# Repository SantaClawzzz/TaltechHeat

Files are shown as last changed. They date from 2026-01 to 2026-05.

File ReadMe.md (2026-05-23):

# Introduction

DIY reflow solder plate controller design, where the actual plate connects with XT30 connector.<br>
Based on this [`PROJECT`](https://github.com/DerSpatz/PCB-reflow-solder-heat-plate)

All PDFs, images, and exports are under the [OUTPUTS](https://github.com/SantaClawzzz/TaltechHeat/tree/master/Outputs) folder

The BOM file is also there and the basket for it is [HERE](https://www.mouser.ee/Tools/SavedCart/Share?AccessID=80928401d5)

## Hardware:<br> 
- **20V 5A max**
- USB-C PD **(Power Delivery)** - `[STUSB4500]`
- MCU programmed with SWD - `[STM32F103C6]`
- 5V switching regulator - `[AP64060ZQ]`

## Pinout

|  User | Pin  |
|---|---|
| BUT1 |  PC13  |
| BUT2 |  PC14  |
| PC15 |  PC15  |

| Signal | Pin  | Function |
|---|---|---|
| SCL | PB8  | I2C1_SCL |
| SDA | PB9  | I2C1_SDA |
| PD_ALERT | PB10 | |
| PD_RST | PB11 | |
| PWM | PB13 | TIM1_CH1N |
| PD_GPIO | PB14 | |
| PD_ATTACH  | PB15 | |
| VCC-DIV | PA3  | ADC1_IN3 |
| TEMP1 | PA4  | ADC1_IN4 | 
| TEMP2 | PA5  | ADC1_IN5 |
| POWER_OK_3 | PA8  | |
| UART1_RX | PA9  | USART1_TX |
| UART1_TX | PA10 | USART1_RX |
| SWDIO | PA13 | SYS_JTMS-SWDIO |
| SWCLK | PA14 | SYS_JTCK-SWCLK |

## Problems

- SWD pins not brought out to headers
- MOSFET too small, can't handle current (PD FET)
- PWM not on PWM capable pin
- Routing issues

- [More detail](https://docs.google.com/document/d/1i9aejrMOuASw6s5gDh6MXbNuGSY3eZ5T1xDJf5HSRbU/edit?tab=t.0)

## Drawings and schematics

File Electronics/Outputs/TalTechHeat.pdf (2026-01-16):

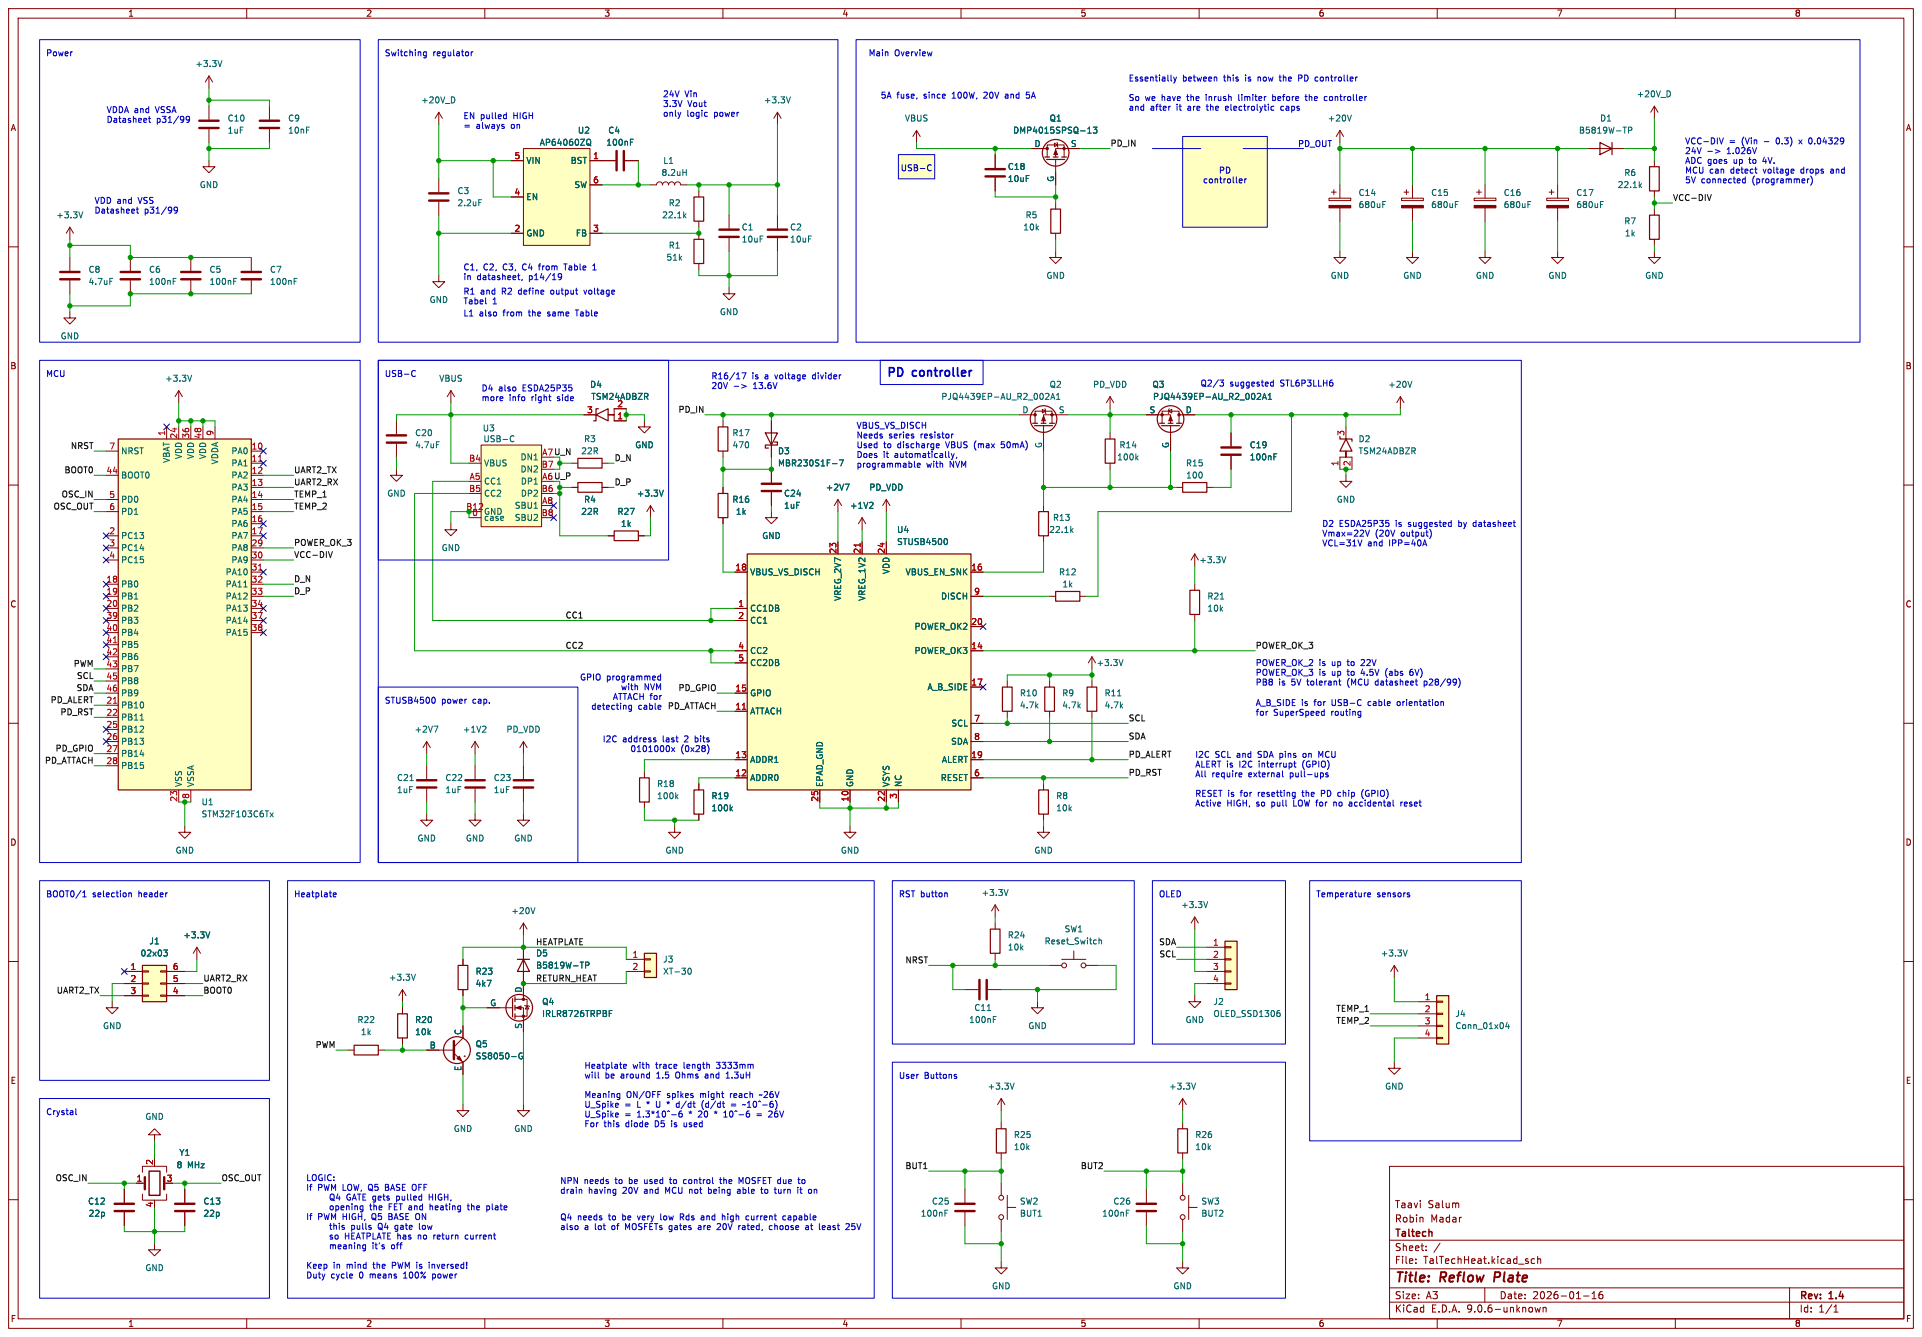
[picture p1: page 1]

24V Vin
3.3V Vout only logic power

controller 5A fuse, since 100W, 20V and 5A

ADC goes up to 4V. MCU can detect voltage drops and

USB-C GPIO programmed with NVM

R1 and R2 define output voltage Tabel 1 C1, C2, C3, C4 from Table 1
4.7uFGND

L1 also from the same Table

1 VDD 24 VSS 23 VDD 36 VSSA
PD_RST OSC_IN

3 VBUS_EN_SNK 16 DISCH 9 POWER_OK2 20 POWER_OK3 14 A_B_SIDE 17 SCL 7 SDA 8 ALERT 19 RESET 6 U4STUSB4500 R12

3 VBUS_EN_SNK 16 DISCH 9 POWER_OK2 20 POWER_OK3 14 A_B_SIDE 17 SCL 7 SDA 8 ALERT 19 RESET 6 R19

A_B_SIDE is for USB-C cable orientation
for SuperSpeed routing

I2C SCL and SDA pins on MCU

drain having 20V and MCU not being able to turn it on Q4 needs to be very low Rds and high current capable

File: TalTechHeat.kicad_sch Sheet: / Taltech Robin Madar Taavi Salum

If PWM HIGH, Q5 BASE ON

also a lot of MOSFETs gates are 20V rated, choose at least 25V

Id: 1/1 Title: Reflow Plate

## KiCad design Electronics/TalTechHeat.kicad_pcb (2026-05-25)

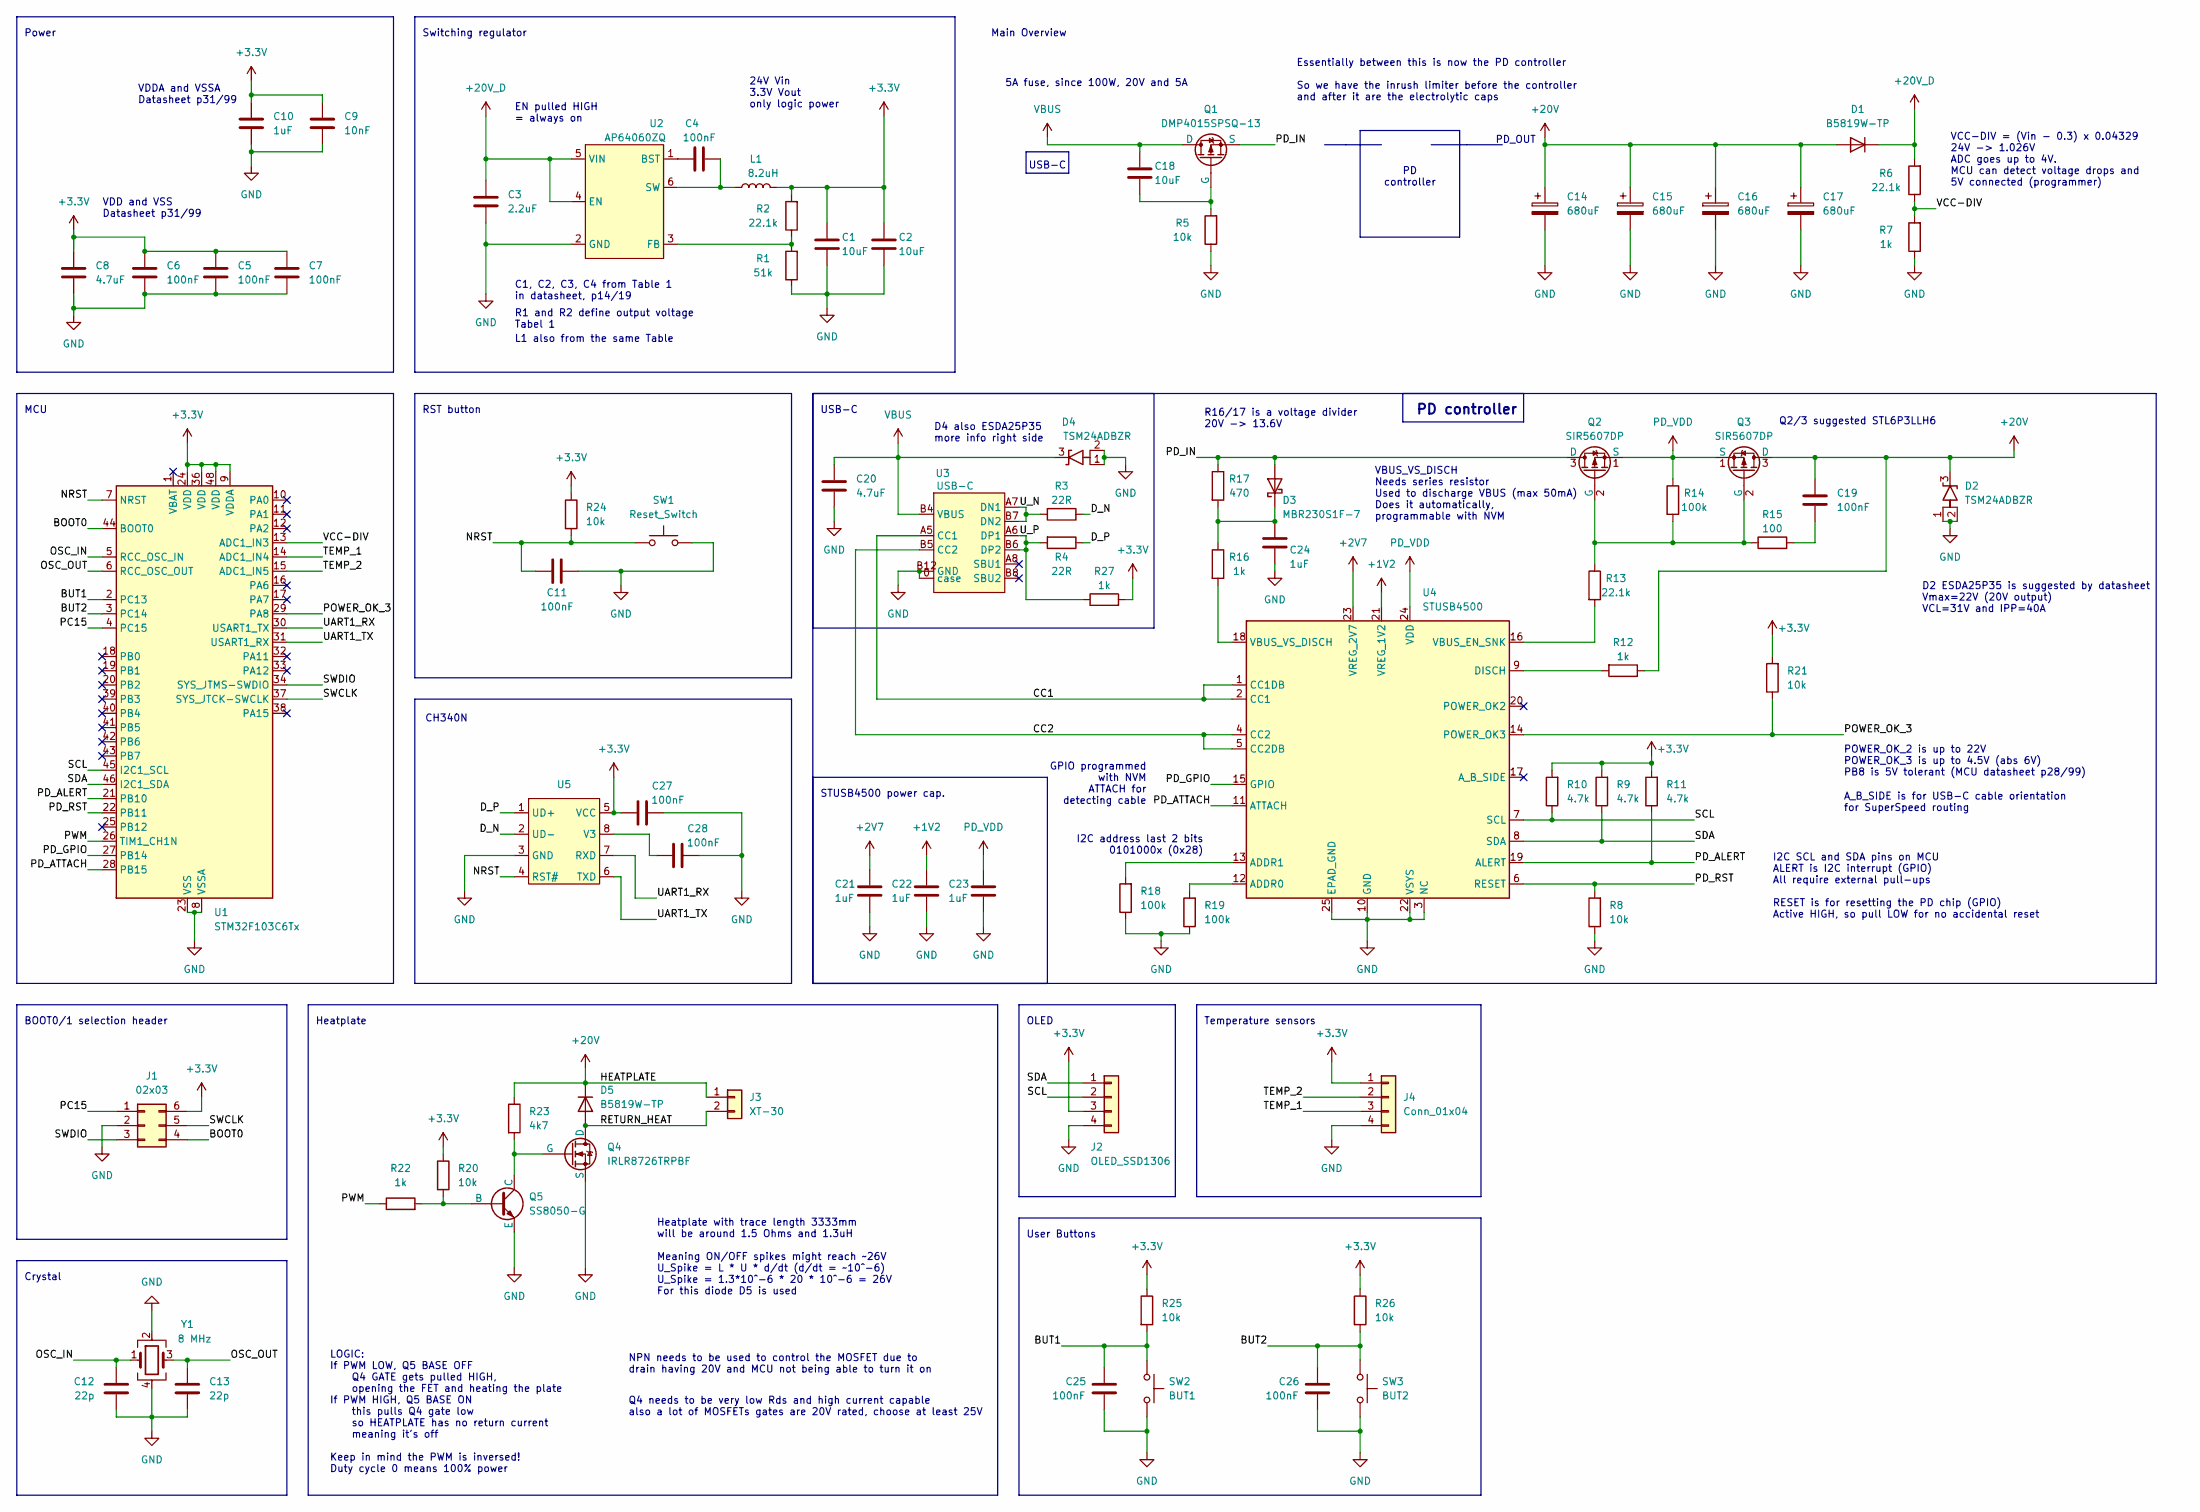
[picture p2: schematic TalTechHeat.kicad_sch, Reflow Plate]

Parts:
C1, C2, C18: 10uF; C_1206_3216Metric_Pad1.33x1.80mm_HandSolder; MPN CL31B106KBHNNNE; Mouser_PN 187-CL31B475KBHNFNE
C3: 2.2uF; C_0805_2012Metric_Pad1.18x1.45mm_HandSolder; MPN CL31B225KBHNNNE; Mouser_PN 187-CL31B225KBHNNNE
C4, C5, C6, C7, C11, C19, C25, C26, C27, C28: 100nF; C_0603_1608Metric_Pad1.08x0.95mm_HandSolder; MPN CL10B104KC8NNNC; Mouser_PN 187-CL10B104KC8NNNC
C8, C20: 4.7uF; C_1206_3216Metric_Pad1.33x1.80mm_HandSolder; MPN CL31B475KBHNFNE; Mouser_PN 187-CL31B475KBHNFNE
C9: 10nF; C_0603_1608Metric_Pad1.08x0.95mm_HandSolder; MPN CL10B103KB8NNNL; Mouser_PN 187-CL10B103KB8NNNL
C10, C21, C22, C23, C24: 1uF; C_0805_2012Metric_Pad1.18x1.45mm_HandSolder; MPN CL21B105KBFNNNE; Mouser_PN 187-CL21B105KBFNNNE
C12, C13: 22p; C_0603_1608Metric_Pad1.08x0.95mm_HandSolder; MPN CL10C220JB8NNNC; Mouser_PN 187-CL10C220JB8NNNC
C14, C15, C16, C17: 680uF; 10mm CAP; MPN UHW1V681MPD; Mouser_PN 647-UHW1V681MPD
D1, D5: B5819W-TP; D_SOD-123; MPN B5819W-TP; Mouser_PN 833-B5819W-TP
D2, D4: TSM24ADBZR; SOT-23-3; MPN TSM24ADBZR; Mouser_PN 595-TSM24ADBZR
D3: MBR230S1F-7; D_SOD-123F; MPN MBR230S1F-7; Mouser_PN 621-MBR230S1F-7
J1: 02x03; PinHeader_2x03_P2.54mm_Vertical; MPN 10129381-906004BLF; Mouser_PN 649-1012938190604BLF
J2: OLED_SSD1306; OLED_128x32; MPN SSD1306 128x32; Mouser_PN (Endal olemas)
J3: XT-30; AMASS_XT30PW-F_1x02_P2.50mm_Horizontal; MPN XT30PW-F; Mouser_PN (Endal olemas)
J4: Conn_01x04; JST_PH_B4B-PH-K_1x04_P2.00mm_Vertical; MPN B4B-PH-K-S(LF)(SN); Mouser_PN 306-B4BPHKSLFSNPP
L1: 8.2uH; L_Vishay_IHLP-2525; MPN IHLP2525BDER8R2M01; Mouser_PN 70-IHLP2525BDER8R2M1
Q1: DMP4015SPSQ-13; DMP4015; MPN DMP4015SPSQ-13; Mouser_PN 621-DMP4015SPSQ-13
Q2, Q3: SIR5607DP
Q4: IRLR8726TRPBF; TO-252.2; MPN IRLR8726TRPBF; Mouser_PN 942-IRLR8726TRPBF
Q5: SS8050-G; SOT-23-3; MPN SS8050-G; Mouser_PN 750-SS8050-G
R1: 51k; R_0603_1608Metric_Pad0.98x0.95mm_HandSolder; MPN RMC16K513FTP; Mouser_PN 791-RMC16K513FTP
R2, R6, R13: 22.1k; R_0603_1608Metric_Pad0.98x0.95mm_HandSolder; MPN RT0603FRE1322K1L; Mouser_PN 603-RT0603FRE1322K1L
R3, R4: 22R; R_0603_1608Metric_Pad0.98x0.95mm_HandSolder; MPN RMC1/16K22R0FTP; Mouser_PN 791-RMC1/16K22R0FTP
R5, R8: 10k; R_0603_1608Metric_Pad0.98x0.95mm_HandSolder; MPN AF0603FR-0710KL; Mouser_PN 603-AF0603FR-0710KL %3D
R7, R12, R16, R22, R27: 1k; R_0603_1608Metric_Pad0.98x0.95mm_HandSolder; MPN CRCW06031K00FKEE; Mouser_PN 71-CRCW06031K00FKEE
R9, R10, R11: 4.7k; R_0603_1608Metric_Pad0.98x0.95mm_HandSolder; MPN RC0603JR-074K7P; Mouser_PN 603-RC0603JR-074K7P
R14, R18, R19: 100k; R_0603_1608Metric_Pad0.98x0.95mm_HandSolder; MPN RCA0603100KFKEC; Mouser_PN 71-RCA0603100KFKEC
R15: 100; R_0603_1608Metric_Pad0.98x0.95mm_HandSolder; MPN RT0603FRE10100RL; Mouser_PN 603-RT0603FRE10100RL
R17: 470; R_0603_1608Metric_Pad0.98x0.95mm_HandSolder; MPN AC0603JR-7W470RL; Mouser_PN 603-AC0603JR-7W470RL
R20, R21, R24, R25, R26: 10k; R_0603_1608Metric_Pad0.98x0.95mm_HandSolder; MPN AF0603FR-0710KL; Mouser_PN 603-AF0603FR-0710KL
R23: 4k7; R_0603_1608Metric_Pad0.98x0.95mm_HandSolder; MPN AF0603FR-074K7L; Mouser_PN 603-AF0603FR-074K7L
SW1: Reset_Switch; SW_Push_1P1T_NO_Vertical_Wuerth_434133025816; MPN 434133025816; Mouser_PN 710-434133025816
SW2: BUT1; SW_PUSH_6mm_H4.3mm; MPN TS02-66-50-BK-100-LCR-D; Mouser_PN 179-TS026650BK100LCR
SW3: BUT2; SW_PUSH_6mm_H4.3mm; MPN TS02-66-50-BK-100-LCR-D; Mouser_PN 179-TS026650BK100LCR
U1: STM32F103C6Tx; LQFP-48_7x7mm_P0.5mm; MPN STM32F103C6T7A; Mouser_PN 511-STM32F103C6T7A
U2: AP64060ZQ; TSOT26; MPN AP64060ZQ; Mouser_PN 621-AP64060ZQWU-7
U3: USB-C; USB4085; MPN USB4085-GF-A; Mouser_PN 640-USB4085-GF-A
U4: STUSB4500; QFN50P400X400X100-25N-D; MPN STUSB4500QTR; Mouser_PN 511-STUSB4500QTR
U5: SOP-8_3.76x4.96mm_P1.27mm
Y1: 8 MHz; ECS-80-12-33Q-GN; MPN ECS-80-12-33Q-GN-TR; Mouser_PN 520-80-12-33Q-GN-TR

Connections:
+1V2: C22.1, U4.21 (VREG_1V2)
+2V7: C21.1, U4.23 (VREG_2V7)
+3.3V: C1.1, C2.1, C5.1, C6.1, C7.1, C8.1, C9.1, C10.1, C27.1, J1.6, J2.3, J4.1, L1.2, R2.2, R9.2, R10.2, R11.2, R20.1, R21.2, R24.1, R25.1, R26.1, R27.2, U1.9 (VDDA), U1.24 (VDD), U1.36 (VDD), U1.48 (VDD), U5.5 (VCC)
+20V: C14.1, C15.1, C16.1, C17.1, C19.1, D1.2 (A), D2.3 (A3), D5.1 (K), J3.1, Q3.3 (D), R12.1, R23.1
+20V_D: C3.1, D1.1 (K), R6.2, U2.4 (EN), U2.5 (VIN)
/BOOT0: J1.4, U1.44 (BOOT0)
/BUT1: C25.1, R25.2, SW2.1, U1.2 (PC13)
/BUT2: C26.1, R26.2, SW3.1, U1.3 (PC14)
/CC1: U3.A5 (CC1), U4.1 (CC1DB), U4.2 (CC1)
/CC2: U3.B5 (CC2), U4.4 (CC2), U4.5 (CC2DB)
/D_N: R3.1, U5.2 (UD-)
/D_P: R4.1, U5.1 (UD+)
/NRST: C11.1, R24.2, SW1.1, U1.7 (NRST), U5.4 (RST#)
/OSC_IN: C12.1, U1.5 (RCC_OSC_IN), Y1.1
/OSC_OUT: C13.1, U1.6 (RCC_OSC_OUT), Y1.3
/PC15: J1.1, U1.4 (PC15)
/PD_ALERT: R11.1, U1.21 (PB10), U4.19 (ALERT)
/PD_ATTACH: U1.28 (PB15), U4.11 (ATTACH)
/PD_GPIO: U1.27 (PB14), U4.15 (GPIO)
/PD_IN: D3.2 (A), Q1.3 (S), Q2.3 (D), R17.1
/PD_RST: R8.2, U1.22 (PB11), U4.6 (RESET)
/POWER_OK_3: R21.1, U1.29 (PA8), U4.14 (POWER_OK3)
/PWM: R22.1, U1.26 (TIM1_CH1N)
/RETURN_HEAT: D5.2 (A), J3.2, Q4.1 (D)
/SCL: J2.2, R10.1, U1.45 (I2C1_SCL), U4.7 (SCL)
/SDA: J2.1, R9.1, U1.46 (I2C1_SDA), U4.8 (SDA)
/SWCLK: J1.5, U1.37 (SYS_JTCK-SWCLK)
/SWDIO: J1.3, U1.34 (SYS_JTMS-SWDIO)
/TEMP_1: J4.3, U1.14 (ADC1_IN4)
/TEMP_2: J4.2, U1.15 (ADC1_IN5)
/UART1_RX: U1.30 (USART1_TX), U5.7 (RXD)
/UART1_TX: U1.31 (USART1_RX), U5.6 (TXD)
/U_N: R3.2, U3.A7 (DN1), U3.B7 (DN2)
/U_P: R4.2, R27.1, U3.A6 (DP1), U3.B6 (DP2)
/VCC-DIV: R6.1, R7.2, U1.13 (ADC1_IN3)
GND: C1.2, C2.2, C3.2, C5.2, C6.2, C7.2, C8.2, C9.2, C10.2, C11.2, C12.2, C13.2, C14.2, C15.2, C16.2, C17.2, C20.2, C21.2, C22.2, C23.2, C24.2, C25.2, C26.2, C27.2, C28.2, D2.1 (A1), D2.2 (A2), D4.1 (A1), D4.2 (A2), J1.2, J2.4, J4.4, Q4.3 (S), Q5.3 (E), R1.1, R5.1, R7.1, R8.1, R18.1, R19.1, SW1.2, SW2.2, SW3.2, U1.8 (VSSA), U1.23 (VSS), U1.35 (VSS), U1.47 (VSS), U2.2 (GND), U3.0 (case), U3.A1 (GND), U3.A12 (GND), U3.B1 (GND), U3.B12 (GND), U4.3 (NC), U4.10 (GND), U4.22 (VSYS), U4.25 (EPAD_GND), U5.3 (GND), Y1.2, Y1.4
unnamed: C19.2, R15.2
unnamed: C24.1, D3.1 (K), R16.1, R17.2
unnamed: C18.2, Q1.2 (G), R5.2
unnamed: Q2.2 (G), Q3.2 (G), R13.1, R14.2, R15.1
unnamed: Q4.2 (G), Q5.1 (C), R23.2
unnamed: Q5.2 (B), R20.2, R22.2
unnamed: C4.1, U2.1 (BST)
unnamed: R1.2, R2.1, U2.3 (FB)
unnamed: C4.2, L1.1, U2.6 (SW)
unnamed: R19.2, U4.12 (ADDR0)
unnamed: R18.2, U4.13 (ADDR1)
unnamed: R12.2, U4.9 (DISCH)
unnamed: R13.2, U4.16 (VBUS_EN_SNK)
unnamed: R16.2, U4.18 (VBUS_VS_DISCH)
unnamed: C28.1, U5.8 (V3)
PD_VDD: C23.1, Q2.1 (S), Q3.1 (S), R14.1, U4.24 (VDD)
VBUS: C18.1, C20.1, D4.3 (A3), Q1.1 (D), U3.A4 (VBUS), U3.A9 (VBUS), U3.B4 (VBUS), U3.B9 (VBUS)

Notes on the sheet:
R16/17 is a voltage divider 20V -> 13.6V
CH340N
PD_OUT
Main Overview
EN pulled HIGH = always on
24V Vin 3.3V Vout only logic power
STUSB4500 power cap.
POWER_OK_2 is up to 22V POWER_OK_3 is up to 4.5V (abs 6V) PB8 is 5V tolerant (MCU datasheet p28/99)
R1 and R2 define output voltage Tabel 1
Q4 needs to be very low Rds and high current capable also a lot of MOSFETs gates are 20V rated, choose at least 25V
NPN needs to be used to control the MOSFET due to drain having 20V and MCU not being able to turn it on
USB-C
PD controller
GPIO programmed with NVM ATTACH for detecting cable
User Buttons
D4 also ESDA25P35 more info right side
LOGIC: If PWM LOW, Q5 BASE OFF Q4 GATE gets pulled HIGH, opening the FET and heating the plate If PWM HIGH, Q5 BASE ON this pulls Q4 gate low so HEATPLATE has no return current meaning it's off Keep in mind the PWM is inversed! Duty cycle 0 means 100% power
Switching regulator
Q2/3 suggested STL6P3LLH6
Heatplate with trace length 3333mm will be around 1.5 Ohms and 1.3uH Meaning ON/OFF spikes might reach ~26V U_Spike = L * U * d/dt (d/dt = ~10^-6) U_Spike = 1.3*10^-6 * 20 * 10^-6 = 26V For this diode D5 is used
C1, C2, C3, C4 from Table 1 in datasheet, p14/19
L1 also from the same Table
A_B_SIDE is for USB-C cable orientation for SuperSpeed routing
VDDA and VSSA Datasheet p31/99
VBUS_VS_DISCH Needs series resistor Used to discharge VBUS (max 50mA) Does it automatically, programmable with NVM
D2 ESDA25P35 is suggested by datasheet Vmax=22V (20V output) VCL=31V and IPP=40A
Crystal
OLED
Essentially between this is now the PD controller So we have the inrush limiter before the controller and after it are the electrolytic caps
Power
VCC-DIV = (Vin - 0.3) x 0.04329 24V -> 1.026V ADC goes up to 4V. MCU can detect voltage drops and 5V connected (programmer)
Temperature sensors
Heatplate
VDD and VSS Datasheet p31/99
MCU
I2C address last 2 bits 0101000x (0x28)
5A fuse, since 100W, 20V and 5A
BOOT0/1 selection header
PD controller
I2C SCL and SDA pins on MCU ALERT is I2C interrupt (GPIO) All require external pull-ups RESET is for resetting the PD chip (GPIO) Active HIGH, so pull LOW for no accidental reset

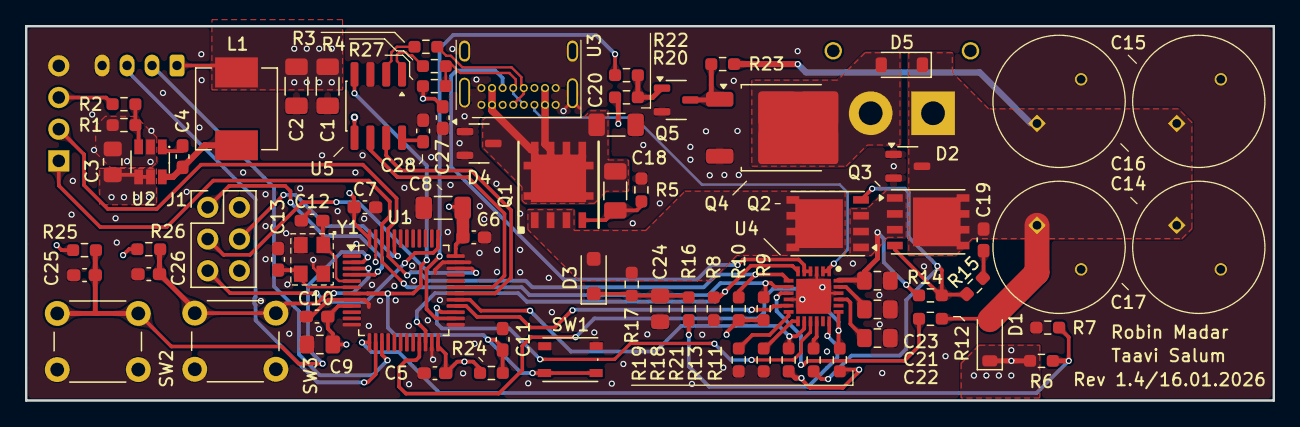
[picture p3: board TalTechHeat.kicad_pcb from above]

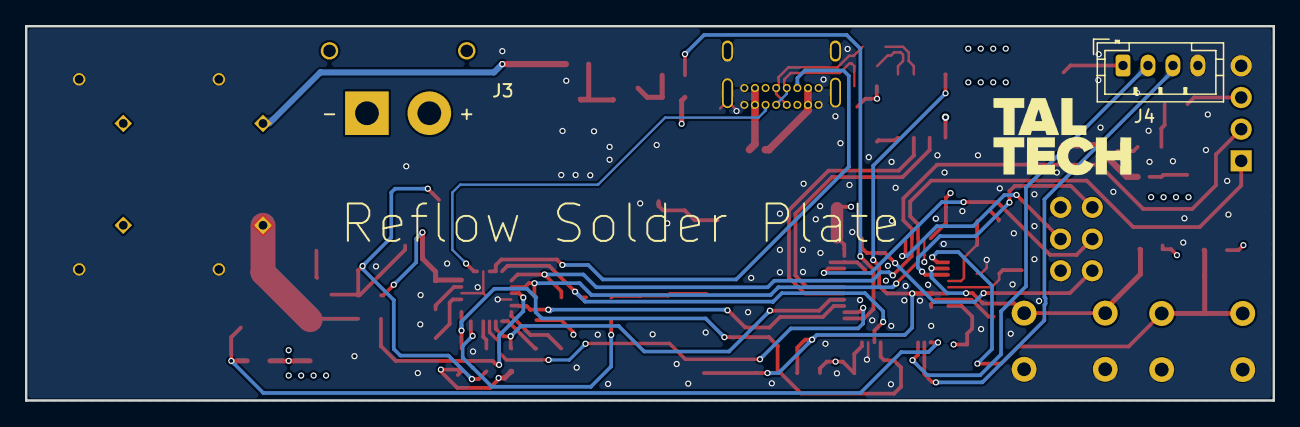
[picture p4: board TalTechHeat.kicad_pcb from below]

Board: 4 copper layers, 100.0 x 30.0 mm, 79 parts (2 on the bottom side), 53 nets.

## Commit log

2026-01-02 Rev 1
    [TalTechHeat.csv, TalTechHeat.kicad_pcb, TalTechHeat.kicad_sch]
2026-01-03 Updated changes Rev 1.1
    [TalTechHeat-B_Cu.gbr, TalTechHeat-B_Mask.gbr, TalTechHeat-B_Paste.gbr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]
2026-01-05 Rev 1.2
    [TalTechHeat-B_Cu.gbr, TalTechHeat-B_Mask.gbr, TalTechHeat-B_Paste.gbr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]
2026-01-05 Added the silkscreen as well
    [TalTechHeat-B_Cu.gbr, TalTechHeat-B_Mask.gbr, TalTechHeat-B_Paste.gbr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]
2026-01-10 Silckscreen changes and BOM changes
    [TalTechHeat.csv, TalTechHeat.kicad_pcb, TalTechHeat.kicad_sch]
2026-01-10 Forgot to update exports
    [TalTechHeat-B_Cu.gbr, TalTechHeat-B_Mask.gbr, TalTechHeat-B_Paste.gbr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]
2026-01-10 Rev 1.3, one resistor and exports update
    [TalTechHeat-B_Cu.gbr, TalTechHeat-B_Mask.gbr, TalTechHeat-B_Paste.gbr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]
2026-01-13 Removed boot1, added UART
    [TalTechHeat.kicad_pcb, TalTechHeat.kicad_sch]
2026-01-16 TaltechPlate folder Rev1, no Titleblock yet
    [TalTechHeat.kicad_pcb, TalTechHeat.kicad_sch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]
2026-01-16 Updated new parts MFN and MPN as well as title block
    [TalTechHeat.kicad_pcb, TalTechHeat.kicad_sch, TaltechPlate.csv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]
2026-01-19 Mounting holes and longer trace on plate
    [TaltechPlate.kicad_pcb, TaltechPlate.kicad_sch]
2026-01-19 Export update
    [TaltechPlate.csv]
2026-02-02 Remove invalid Windows path files
    [TalTechHeat-B_Cu.gbr, TalTechHeat-B_Mask.gbr, TalTechHeat-B_Paste.gbr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]
2026-02-02 removed broken kleplace
    [TalTechHeat-B_Cu.gbr, TalTechHeat-B_Mask.gbr, TalTechHeat-B_Paste.gbr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]
2026-05-23 Fixes implementation 1/2
    [TalTechHeat.kicad_pcb, TalTechHeat.kicad_sch]
2026-05-25 Fet replace and directory change
    [TalTechHeat-B_Cu.gbr, TalTechHeat-B_Mask.gbr, TalTechHeat-B_Paste.gbr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]
